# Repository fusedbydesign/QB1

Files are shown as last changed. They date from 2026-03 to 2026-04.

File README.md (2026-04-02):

# QB1

QB1 is a rapid prototyping system for ESP32 devices. The system was designed for ESPHome sensors, but it could potentially be used for other applications.

## Features

* Rapid prototyping for testing sensors and automation in the intended environment.
* Modular design allows each device to be built with the appropriate sensors, power interface, and mounting solutions. The five cube faces can each be used for a different purpose. 
* The QB1 specification allows multiple sensors to exist on the same device without conflict.
* Easy to make. 
  * The enclosure can be produced using a low cost 3D printer. 
  * The main board can be assembled quickly with basic soldering skills.
  * Many common sensor can be integrated by printing a custom face plate and connecting the sensor to the main board with Dupont wire. 
* Once constructed, the device can be modified without soldering, enabling rapid modification of devices. 

## Example Projects

<table>
  <tr>
    <td>
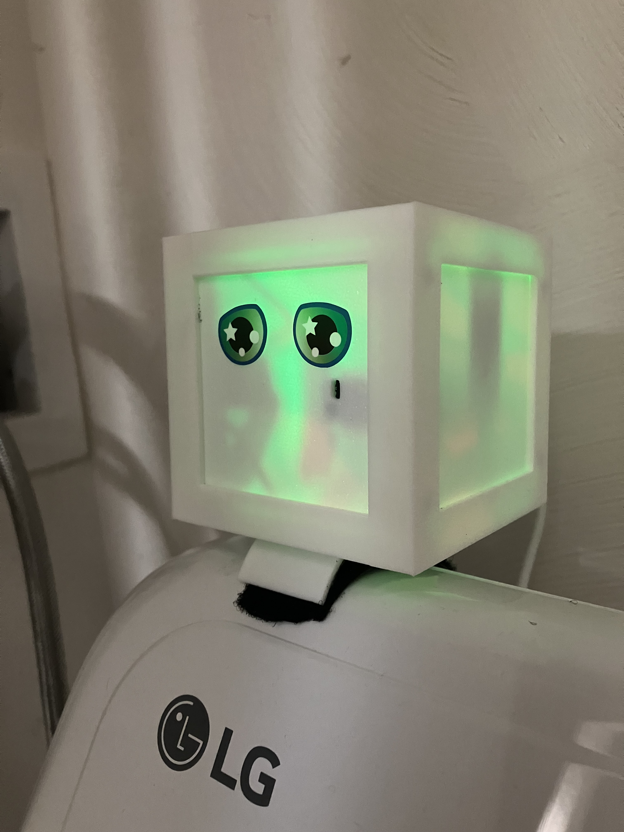
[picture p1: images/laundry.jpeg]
laundry minder project image
      <br>
      Washing machine monitor using SW-420 vibration sensor to detect when the machine is running and V53L0X distance sensor to tell when lid has been opened. The device is mounted to the washing machine using a custom mounting plate and velcro tape, and it is used to send a notification when wet clothes have been left in the wachine machine. 
    </td>
    <td>
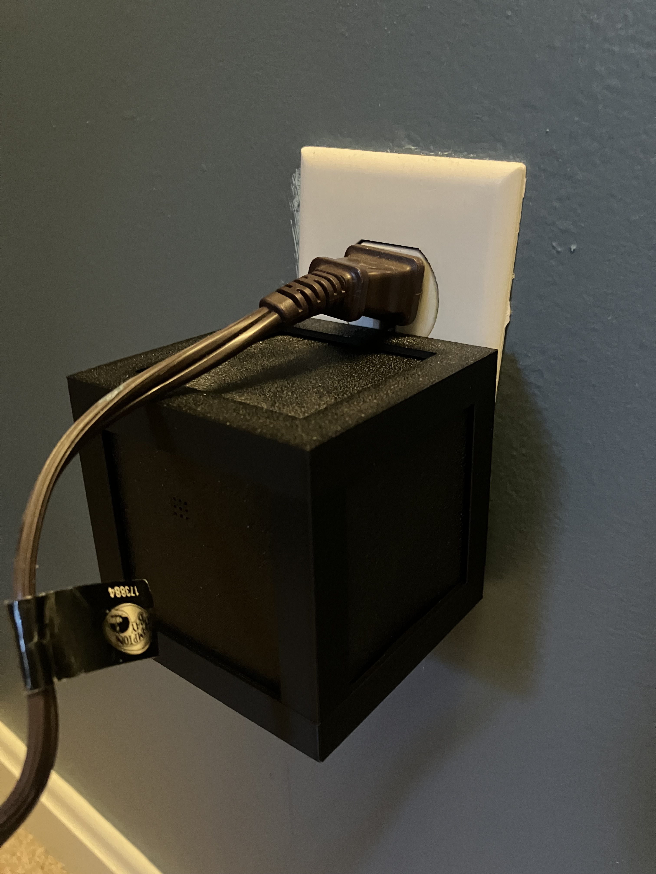
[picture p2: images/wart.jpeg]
wall wart project image
      <br>
      Plug-in temperature and humidity monitor using SHT40. The device plugs in to the wall using an off-the-shelf USB wall plug that is inside the QB1 enclosure and held in place using a custom face plate. 
    </td>
  </tr>

  <tr>
    <td>
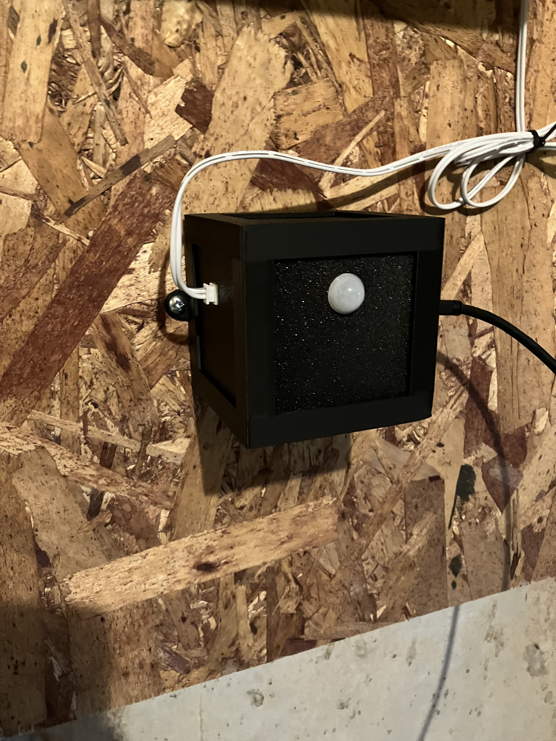
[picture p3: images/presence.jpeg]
human presence project image
      <br>
      A wall-mounted human presence sensor that combines an AM312 PIR motion sensor and a wired magnetic reed door sensor. The device is used turn on/off lights in the area based on human presence. 
    </td>
    <td>
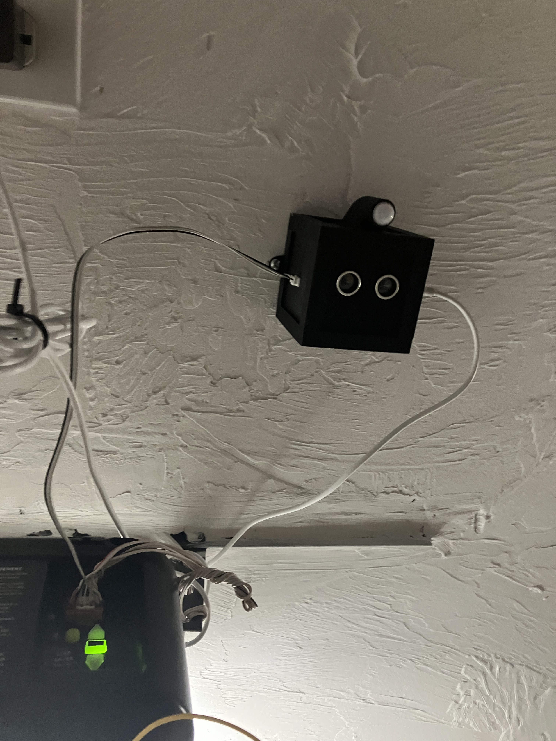
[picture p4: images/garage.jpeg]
garage project image
      <br>
      A ceiling-mounted device that combines human presence detection using an AM312 PIR motion sensor, car presence detection using an HC-SR04 distance sensor, and garage door control/status using a <a href="https://github.com/PaulWieland/ratgdo">ratgdo-compatible</a> peripheral board. 
    </td>
  </tr>
</table>

## Building

The core QB1 components can be built with basic tools and skills. 

> [!WARNING]
> This is an open source project and a constant work in progress, not a finished product. Production files and PCBWay projects are provided only for convenience. Boards ordered using these files/projects may have flaws due to issues in the design or assembly. The maintainers of this project are not responsible for loss or damages due to these flaws. Please submit any issues you find using the issue tracker for this project.  

### Tools Required

* A [soldering iron](https://amzn.to/4105tMp) and related supplies. The QB1 main board contains only through hole components, so only basic soldering skills are required. Some peripheral boards require surface mount components and more advanced soldering skills. 
* A basic 3D printer to print the QB1 enclosure and face plates. Using a print-on-demand service (or a friend with a printer) can help get you started, but having your own printer makes it much easier to print new faceplates to modify the device in the future. The [Bambu Lab A1 Mini](https://bambulab.com/en/a1-mini) (without AMS) is inexpensive and well-suited to printing smaller items like the QB1 enclosure. 
* A small Phillips screwdriver (or driver matching the head of the screws, if not Phillips). The shaft must be smaller than 5.5 mm in diameter in order to fit in the holes in the bottom of the enclosure. 
* A small tube of super glue to build some of the enclosure parts. 
* (Optional) A [hot glue gun](https://amzn.to/40Knkqm). Many sensors that operate at 3.3v can be connected directly to the main board using Dupont wire. It's best to glue these connectors in place so they don't fall off in operation. The hot glue can easily be removed later. 

### Components Required

All components other than custom circuit boards and 3D-printed enclosure parts can be purchased in small quantities from Amazon or AliExpress.

* A QB1 main board. You can order a small batch of 5 main boards using this [PCBWay project](https://www.pcbway.com/project/shareproject/QB1_Main_Board_for_ESP32_Development_Kit_a3892956.html). You can also use the zipped Gerber files provided in a QB1 release to order the board from another supplier. 
* A [30-pin ESP32 development board](https://amzn.to/4lGmVin) with USB-C connector. You can choose a device with the right storage and other features for your application.
* (7) [Female 15-pin, single row board header with 2.54 mm pin spacing](https://amzn.to/4suHbWA). You will need two for the ESP32 dev kit socket and up to 5 for the remaining QB4 faces.
* [Screws](https://amzn.to/47RIYwE): M3, self-tapping, coarse threaded with pan/button head. The head must be between 3.5mm and 5.5mm in diameter.
  * (8) To secure the main board and close the case, use screws that are 8mm long (not counting the head), but screws up to 16 mm in length will also work.
  * (4, Optional) To make the top plate removable and functional, use screws that are exactly 8mm long (not counting the head). In most cases, the top plate is not used for sensors or other peripherals, because the four side plates are sufficient. In this case, it can be glued in place, and these screws are unnecessary.
* [Printed enclosure parts](https://makerworld.com/en/collections/23142249-qb1): A top, a bottom, face plates for mounting and peripherals, and blank plates to cover any remaining faces. 
* (Optional) Any additional components required for peripherals. See peripheral doc for mor information. Some generally useful items to have on hand are:
  * [Dupont wire](https://amzn.to/4slY8CT) with male connector on one end and female connector on the other. The wire should be between 10 and 20cm in length. This wire is useful for hooking up small sensors that do not require a QB1 peripheral board. 
  * [Small prototyping boards](https://amzn.to/4sSRvYk) (e.g 40 mm by 60 mm) can be used to develop peripheral boards.  

### Assembling the Boards

Follow the instructions provided to assemble the QB1 [main board](/mainboards/ESP32DK) and any peripheral boards.

### Assembling the QB1

* Insert the ESP32 development board into the pair of 15-pin sockets on the bottom of the QB1 main board. Use the labels on the PCB silk screen to orient the ESP32 board correctly.  
* Place the main board on the tall screw hole supports inside the enclosure bottom. Ensure that the board is oriented correctly so that the ESP32 dev board screw holes rest on the lower supports and the USB-C connector faces the opening on the bottom plate. Screw the main board in place with 4 M3 screws.
* Place the USB-C port cover in the enclosure bottom and glue it in place with super glue. 
* Attach peripherals
  * For peripherals that are attached by wires, plug the connector into the appropriate place in the main board. Secure the connectors in place using hot glue, and attach the peripheral to its custom face plate.  
  * Attach peripheral boards to their custom plates. These boards typically have male header that connects to the main board and is held in place by the enclosure. This connection will be made when the face plates are inserted in a later step.
* Place the QB1 enclosure top upside down on a flat surface.
* Insert a face plate into the QB1 top face. The plate will be held lightly in place by friction against the screw supports. To hold this plate more firmly, place two top plate holders over the plate and screw them in place. 
* Place face plates into the four slots at the top of the enclosure. 
* Place the QB1 enclosure bottom upside down onto the top. To ensure that the peripheral boards are attached correctly to the main board connector: lift each perhipheral board slightly to make the connection, then lower the enclosure bottom after all connections are made. It may be necessary to wiggle the legs of the enclosure top to ensure that they are seated correctly. 
* Screw the bottom to the top using 4 M3 screws. 

## FAQ

* **When would I use this?** QB1 is useful in a few circumstances: 
  * When you want to quickly prototype a device to test its behavior in the intended environment. 
  * When you need multiple sensors in a single device.
  * When you need to deploy sensors in a basement/garage or other utility area where appearance/size is less important.
* **When wouldn't I use this?** There are some limitations:
  * QB1 is nearly 80 mm long on each side. For many applications, a custom board and enclosure would be smaller. 
* **How do I use this for home sensing and automation?** See the [ESPHome site](https://esphome.io) for more information. A typical solution is to set up a [Home Assistant](https://www.home-assistant.io) hub that takes information from QB1 devices (and other sensors). 
* **Does the QB1 look good?** Looks are subjective, but yes. 
* **What sensors are supported?** Any sensor that operates at 3.3v and has a fairly simple interface (a few IO pins, I2C, SPI, etc.) can be wired directly to the appropriate pins on the QB1 main board. Then all that is needed is a face plate that holds the sensor in place. Sensors/components with more complicated interfaces can be integrated by developing a peripheral board with additional interface components. 
* **How do I add an external connector?** The best ways to achieve this are:
  * Locate a panel-mount connector and attach it to the main board using wires.
  * Make a simple peripheral board with connectors soldered to it. A male JST-XH connector soldered to a peripheral board will sit approximately flush with the face plate. 
* **How do I configure ESPHome?** Locate ESPHome documentation for the sensor you would like to configure. Look at the main board documentation or silk screen markings on the main board to determine which pins are attached to each connector position. 
* **What happens if I plug in multiple peripherals? How do I keep them from conflicting?** The QB1 spec assigns pins to each peripheral position. Some pins are shared, such as pins intended for the I2C and SPI buses. Each peripheral position also has four pins that are dedicated to that position (with the exception of EB2 and EB5, that have the same set of "dedicated" pins). Where possible, a peripheral should use dedicated pins or buses in order to avoid conflict.
* **The screws are too tight/loose. What is wrong?** To keep the part count low, the design does not use screw inserts, and instead uses self-tapping screws that screw into 3D-printed holes. Due to variation in printers and settings, these holes may be slightly too large/small. To fix it:
  * If the hole is too tight, carefully drill it out. Forcing the screw in without drilling may cause the plastic to crack.
  * If the hole is too loose, add a small amount of hot glue, allow the glue to cool, then screw in the screw. Hot glue can also be used to repair screw holes that are cracked or worn out. 
* **What options should I select when ordering boards from PCBWay?** Unless you have a compelling reason to change the options, you can use the default settings when ordering boards. 
* **How can I get a QB4 if I don't have a 3D printer or soldering iron?** There are a few options:
  * Order assembled boards and printed enclosure parts from an electronics fab and print-on-demand service, respectively.
  * Join a local maker space that has 3D printers and electronics assembly tools. 
  * Find someone near you with a 3D printer and buy enclosure parts from them. Many people who own a 3D printer would be thrilled to print something for you in exchange for a small amount of money to pay for their filament habit. 
  * Use this project as an excuse to buy what you need. Soldering supplies are inexpensive. Small/basic 3D printers are now cheap and reliable enough that they should be considered essential tools for any homeowner. 

## Support and Transparency

If you are fortunate enough to have a store near you that sells basic electronics components, please consider buying components from them instead of using the links on this site or ordering from internet retailers.

I (the developer of QB1) earn a commission from tools and components purchased though links on this site. As an Amazon Associate, I earn from qualifying purchases. I also earn a commission from circuit boards ordered from PCBWay. I chose the recommended tools/components by searching for products with the correct specs and features, but I haven't tried them all. Please review the product description, specs, reviews, etc. before ordering.

If you would like to directly support the development of QB1, you can donate using [Buy me a coffee](https://buymeacoffee.com/fusedbydesign).

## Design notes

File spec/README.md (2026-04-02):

# QB1 Specification

The QB1 specification governs the physical and electrical characteristics of QB1 and its peripherals. The specification ensures that compliant peripherals will fit in the enclosure and will not interfere with other peripherals. 

## Electrical Specification

### Peripheral Connector Pins

The 15-pin peripheral connector has the following pin connections:

| Pin # | Name | Description |
|---|---|---|
| 1 | AUX | Auxiliary connection shared between all peripherals, not connected to ESP32 |
| 2 | S | Shared connection between all peripherals and connected to ESP32 |
| 3 | MOSI | SPI MOSI |
| 4 | MISO | SPI MISO |
| 5 | CLK | SPI CLK |
| 6 | EN | ESP32 enable pin which allows the peripheral to reset the ESP32 |
| 7 | SCL | I2C SCL |
| 8 | SDA | I2C SDA |
| 9 | 3V3 | 3.3V power|
| 10 | GND | Ground |
| 11 | VIN | 5V power|
| 12 | PIO4 | Peripheral I/O 4 |
| 13 | PIO3 | Peripheral I/O 3 |
| 14 | PIO2 | Peripheral I/O 2 |
| 15 | PIO1 | Peripheral I/O 1 |

The mapping between these pins and ESP32 pins is not part of the spec, and is specific to each main board implementation. This mapping can be found in the main board documentation. 

#### AUX

The AUX pin is intended to carry power/signals between all peripherals without using the host. For example, it could carry an analog signal or higher voltage/current power. The use of this pin is not governed by the spec. 

#### S

The S pin carries a signal that is shared between all peripherals and the host. The use of this pin is not governed by the spec.

#### SPI Pins

The MOSI, MISO, and CLK pins are used to construct a SPI bus controlled by the host. The slave select (SS) should be implemented using a PIO pin, so it will be different for each peripheral. A spec-compliant peripheral should only use the MOSI, MISO and CLK pins as a full duplex, single-width SPI bus.  

#### I2C Pins

The SCL and SDA pins are used to construct an I2C bus controlled by the host.  A spec-compliant peripheral should only use these pins as an I2C bus. The spec does not govern how addresses are assigned, and peripherals should support address changes to allow multiple peripherals of the same type to be attached at the same time. 

#### Power Pins

The 3V3 pin provides 3.3V during operation. The VIN pin may provide 5V, or it may be unconnected, depending on the configuration. The user must ensure that only one power supply is connected to either VIN or 3V3, originating from the main board or a peripheral. When 5V is supplied to VIN, the main board will produce 3.3V and supply it to the 3V3 pin.  

#### PIO Pins

The peripheral I/O (PIO) pins are used to make a separate connection between the host and each peripheral in a standardized way. For example, two peripherals can be installed that both use PIO1 and PIO2 to communicate directly with the host. These pins will be mapped to different host pins for each peripheral location. 

The PIO pins have the following features and allowed uses:

| PIO # | Input to host | Output from host | Internal pull-up | Analog input to host | Capacitive touch input to host | 
|:---:|:---:|:---:|:---:|:---:|:---:|
| PIO 1 | X | X | X | | |
| PIO 2 | X | X | X | X | X |
| PIO 3 | X | | | | |
| PIO 4 | (1) | X | (1) | (1) | (1) |

1. PIO 4 supports input to the host with pull-up, analog, and touch, but it may also be connected to strapping pins on the host, requiring it to be in a high-impedance state during host boot. This pin shall only be used as an input to the host after the host has booted. 

### Power

The specification allows two power configurations:
* In the full power configuration, power is supplied to both the 5V and 3.3V rails. All spec-compliant peripherals can be used in this configuration.
* In the low power configuration, power is only fully supplied to the 3.3V rail. This configuration should be used when the device is powered by a battery, or otherwise has power limitations. Peripherals should work in low power mode, if possible, but this mode will not support peripherals that require 5V. A low power device may supply power to the 5V rail, but attached low-power peripherals must not draw power from this rail.  

#### Supply

A compliant power source must supply exactly one of the following to the QB1 main board:
* 5V at 2A (full power)
* 3.3V at 1A (low power)

#### Draw

A compliant peripheral must draw at most:
* 5V at 200mA
* 3.3V at 100mA

A single peripheral may draw from both power rails simultaneously. In order to support the low power configuration, a peripheral should not draw power from the 5V rail. 

If a peripheral requires more power than allowed by the spec, it may power itself and also act as a power supply to the QB1. For example, the peripheral could accept 5V at 3A, use 1A for its purposes, and provide the remaining 2A to the QB1 via VIN. The power supply could also send power to other peripherals using AUX, but the use of AUX for this purpose is outside of the spec. 

#### Absolute Maximum

The absolute maximum voltage and current that may be supplied over AUX is 12V and 3A. 

## Physical Specification

The physical specification is a set of dimensions that affect peripheral fit.

| Dimension | Value | Notes| 
|---|---|---|
| A | 3.4 mm | Distance from center of peripheral connector to inside of window plate. |
| C | 2 mm | Window plate thickness |
| D | 50 mm | Usable window height and width |
| E | 34 mm | Usable window height above main board connector |
| F | 62 mm | Maximum peripheral board width |
| G | 38 mm | Maximum distance from top of main board connector to top of peripheral board |
| H | 6 mm  | Maximum distance from top of main board connector to bottom of peripheral board |
| I | 2.4mm | Maximum peripheral board thickness |

Additional notes:
* When a peripheral board is mounted in the inside position, it may interfere with adjacent boards if it is wider than 40mm. 
* A peripheral board mounted in the inside position of the top plate may interfere with boards mounted in side plates that are taller than 28mm from the top of the main board connector. 
* A peripheral board mounted in the outside position of the top plate may interfere with boards mounted in side plates that are taller than 36mm from the top of the main board connector. 
* The spec does not govern the use of space behind the peripheral board. For best results, peripherals should use space toward the center of the usable window area, and provide options that help prevent interference with nearby peripherals (e.g. multiple face plates that place the peripheral in slightly different positions).

## Component Guidelines

Where possible, QB1 main boards, peripherals, and enclosure pieces should allow component sourcing and assembly by hobbyists. This section contains guidelines, but these are not required to be followed for spec compliance. 

* When screws are required, use M3 self-tapping coarse thread screws with 8mm of thread length. 
* Use through-hole electronic components, if possible.

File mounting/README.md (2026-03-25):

# QB1 Mounting

This document lists QB1 mounting hardware and other physical solutions.

## Mounting

* A face plate is available that allows the QB1 to be [mounted to a wall or ceiling](https://makerworld.com/en/models/2566908-qb1-wall-ceiling-mount-plate) using screws.

## Miscellaneous

* QB1 faces that are not used for peripherals or mounting can be covered with [blank face plates](https://makerworld.com/en/models/2543181-qb1-blank-face-plate).

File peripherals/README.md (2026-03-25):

# QB1 Peripherals

This document lists peripherals that are supported by QB1. This list is not comprehensive, and adding support for a 3.3v sensor is usually a simple matter of developing a face plate for it. 

## Sensors

### Distance

* [HC-SR04](HCSR04). An ultrasonic distance sensor with a range of 2cm to 4m and an accuracy of 3mm. Interfaces to QB1 using a peripheral board. 
* [VL53LOX](https://makerworld.com/en/models/2572612-qb1-vl53lox-plate). A time-of-flight laser distance sensor with a range of 30mm to 2m and an accuracy of +/- 3%. Connects directly to QB1 using wires. 

### Motion/Presence

* [AM312](https://makerworld.com/en/models/2547169-qb1-am312-plate). A PIR motion sensor that detects humans and pets up to 5m away. Connects directly to QB1 using wires. An [angled mounting plate](https://makerworld.com/en/models/2548871-qb1-am312-plate-angled) is also available.

### Environmental

* [SHT40](https://makerworld.com/en/models/2571182-qb1-sht40-plate). A temperature and humidity sensor with an accuracy of +/- 0.2 degrees C and +/- 1.8% RH. Connects directly to QB1 using wires. 

### Vibration  

* [SW-420](https://makerworld.com/en/models/2572635-qb1-sw-420-plate) vibration sensor. Connects directly to QB1 using wires.

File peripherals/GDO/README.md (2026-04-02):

# Garage Door Opener Board for QB1

The Garage Door Opener (GDO) board allows the QB1 to directly interface with Chamberlain/Liftmaster garage door openers that cannot be controlled with dry contacts. 

This peripheral is inspired by the [ratgdo](https://ratcloud.llc), and it is designed to be compatible with [ratgdo firmware](https://paulwieland.github.io/ratgdo/flash.html). If you simply want to connect your garage door opener to your home automation system, please consider buying a ratgdo board. Some models even include additional components that make it easy to solve additional garage sensing/control problems (car presense, parking distance) with the ratgdo. The QB1 GDO peripheral is designed for circumstances in which a ratgdo needs to be combined with other sensors/peripherals. It can also be used to address unusual power or mounting circumstances. 

The schematic and technical information used to develop this project are due to the [rat-ratgdo project](https://github.com/Kaldek/rat-ratgdo). 

## Printed Circuit Board

The easiest way to get the PCB is to order a batch using this [PCBWay project](https://www.pcbway.com/project/shareproject/QB1_garage_door_opener_peripheral_board_5e12e1d1.html). This project can also be used to purchase assembled boards. 

> [!CAUTION]
>Assembling this peripheral is somewhat challenging because it is necessary to obtain and solder surface mount components. The soldering is possible with a normal soldering iron with a fine tip. Search on YouTube for instructional videos. You will probably also want additional tools such as a vise, a desk-mounted magnifying glass, and tweezers. 

## Required components

| Count | Description |
|---|---|
| 1 | 3-pin male JST-XH PCB connector, through hole, straight |
| 1 | 2N7002 transistor, surface mount, SOT-23 |
| 2 | AO3400A transistor, surface mount, SOT-23 |
| 3 | 10k Ohm resistor, surface mount, 0805, 1%, 1/4W |
| 1 | 15-pin male header with 2.54mm spacing, angled, 6mm mating length, 3mm tail length |
| 1 | (Optional) 2-pin male header with 2.54mm spacing, straight, 6mm mating length, 3mm tail length| 
| 1 | (Optional) 2-pin jumper with 2.54mm spacing | 

It is also necessary to obtain a wire to connect the peripheral to the terminals on the garage door opener. The best way to do this is to crimp a female JST-XH connector onto one end of a ribbon or set of wires, and leave the other end bare so the wires can be attached to the terminals on the garage door opener. See the board silk screen to determine the proper connections. 

## Assembly

1. Place and solder the the surface mount components on the front side of the board. 
1. Place and solder the 3-pin JST connector, after selecting the appropriate location. 
  * To allow the peripheral to be installed in a side face of the QB1 (the most common mounting), the connector should placed in the location marked J4 on the back side of the board.
  * The connector can be soldered in other positions, or even left off the board, to support less common methods of mounting the board and connecting to the garage door opener. 
1. Place and solder the 15-pin angled header on the front side of the board. The board may not have silk screen markings to indicate the correct side of the board for the header. It should be placed on the same side as the surface mount components.  
1. (Optional) place and solder the 2-pin male jumper at position J2 on the front of the board. 

The 2-pin male header is used to optionally connect the CTRL signal from the garage door opener to the QB1 AUX line. This optional connection can be made by placing a jumper on the header. The connection allows other peripherals to use the CTRL signal (e.g. to make a power supply).

The peripheral board mounts to the main board in the outside position, which allows the JST-XH connector to sit roughly flush with the window. 

## Enclosure

A [face plate](https://makerworld.com/en/models/2606454-qb1-plate-for-garage-door-opener-peripheral-board) is available for this peripheral. Attach the peripheral board to the face plate using 4 M3x8mm self-tapping screws. 

## Operation

The easiest way to use the GDO peripheral is to start with the appropriate [ratgdo firmware](https://paulwieland.github.io/ratgdo/flash.html) and modify the configuration so that the firmware communicates with the GDO using the correct pins. See the silk screen on the peripheral board for the connection between the GDO and QB1 connector. Also see the [main board README](/mainboards/ESP32DK) for the mapping between QB1 connector pins and ESP32 pins.  

The ESPHome ratgdo firmware is available on github, and there is also a convenient [downloader](https://ratgdo.github.io/esphome-ratgdo/). Any firmware that uses the correct host SoC family (e.g. ESP32 for the QB1 ESP32 dev kit main board) should work after the pins are correctly configured. The ESPHome configuration can then be modified to enable additional peripherals on the device.

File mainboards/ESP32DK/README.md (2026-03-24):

# QB1 ESP32 Dev Kit Main Board

The ESP32 Dev Kit Main Board adapts a 30-pin ESP32 dev dev to the QB1. This is the main component required to build a QB1 using an ESP32 dev kit. 

## Printed Circuit Board

The easiest way to get the PCB is to order a batch using this [PCBWay project](https://www.pcbway.com/project/shareproject/QB1_Main_Board_for_ESP32_Development_Kit_a3892956.html). You can also get an assembled board, but the board has been designed to make DIY component sourcing and assembly very easy.  

## Required components

| Count | Description |
|---|---|
| 7 | Female header with 2.54mm spacing, 15-pin |

## Assembly

* Solder 15-pin female header connectors to the locations on indicated for the ESP32 dev kit, and also to any peripheral locations that will be used. Note that connectors for the dev kit go on the bottom of the board, while the connectors for the peripherals go on the top. Use the PCB silk screen as a guide, and only place connectors where the holes are surrounded by a border on the silk screen.  
* Solder additional connectors for power and reset connections, as needed. In many cases, these connectors are unnecessary. These connectors are only necessary if you want to add a poer source or reset switch without using one of the peripheral spots.  

## Enclosure

Print or otherwise obtain the [enclosure bottom](https://makerworld.com/en/models/2543156-qb1-bottom-for-esp32-dev-kit-main-board) to incorporate this main board into a QB1. To complete the enclosure, you will also need a top piece and window pieces/blanks. All QB1 enclosure pieces are available in [this collection](https://makerworld.com/en/collections/23142249-qb1).

## Operation

### Power

Power can be supplied to this board through the USB connector on the development kit, or by a power supply peripheral. When powering by USB, the USB power supply must provide at least 2A for the full power configuration, or 1A for low power configuration. See the [QB1 specification](/spec) for more information about power configurations. 

### Connectors

This main board has four peripheral connectors labeled EB1-5. EB5 is in the center of the board, and it can be used to wire up a peripheral mounted to the top plate. All connectors are wired to different host pins for PIO, except for EB2 and EB5, which share the same host pins for PIO. So peripherals that use (the same) PIO pins cannot operate in EB2 and EB5 at the same time. 

### Pin Mapping

| Pin # | Connector | Host |
|---|---|---|
| 1 | AUX | Not Connected |
| 2 | S | D25 |
| 3 | MOSI | D23 |
| 4 | MISO | D19|
| 5 | CLK | D18 |
| 6 | EN | EN |
| 7 | SCL | D22 |
| 8 | SDA | D21 |
| 9 | 3V3 | 3V3 |
| 10 | GND | GND |
| 11 | VIN | VIN |

| Pin # | Connector | Host EB1 | Host EB2 | Host EB3 | Host EB4 | Host EB5 |
|---|---|---|---|---|---|---|
| 12 | PIO4 | D12 | D4 | D2 | D15 | D4 |
| 13 | PIO3 | D36 | D39 | D34 | D35 | D39 |
| 14 | PIO2 | D27 | D13 | D14 | D33 | D13 |
| 15 | PIO1 | D16 | D17 | D26 | D32 | D17 |

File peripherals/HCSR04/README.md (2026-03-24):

# HC-SR04 Distance Sensor Peripheral Board for QB1

The HC-SR04 is a low-cost ultrasonic distance sensor with sub-centimeter precision and a maximum range of 4 meters. Unfortunately, it needs to operate at 5V for best performance, and its output must be converted to 3.3V in order to interface with the ESP32 without damaging it. This board provides a safe, reliable 5v/3.3V interface between the ESP32 and an HC-SR04. The board also provides a physical mounting surface for the HC-SR04, and a second level converter that can be used to connect another HC-SR04 that is mounted elsewhere. 

> [!TIP]
> There are other distance sensors that can interface more easily with the QB1 without level conversion. There are also HC-SR04P modules that can be powered using 3.3v, but the maximum range will be slightly reduced. Be prepared to test multiple distance sensors to find the ones that work best for your application.

## Printed Circuit Board

The easiest way to get the PCB is to order a batch using this [PCBWay project](https://www.pcbway.com/project/shareproject/QB1_peripheral_board_for_HC_SR04_distance_sensor_22c7cf84.html). Due to the options for mounting the sensor module, and the unusual way the module is mounted in some options, DIY assembly is highly recommended. Assembly only requires a few through hole components and some basic soldering skills. 

## Required components

| Count | Description |
|---|---|
| 1 | [HC-SR04 module](https://amzn.to/4rNMYFK)|
| 1 | 15 pin male header, 2.54mm pin spacing, angled |
| 2 | 100k Ohm resistor, through hole, axial |
| 2 | 51k Ohm resistor, through hole, axial |
| 4 | Single pin male header, straight |
| 1 | (Optional) 4-pin male header, 2.54mm spacing, angled | 

Component notes:
* For the angled header, you can use commonly-available [breakaway header](https://amzn.to/4sulC8Q) and break it to the correct size. Ensure the header has a short post (the straight part---approximately 3mm long) and a longer tail (the bent part---approximately 6mm long after the bend). The post of the header is soldered to the board and the connector sits 4-5mm off the board. These dimensions ensure a proper fit using the face plate for this connector. Other connectors may be used by modifying the face plate.
* Any [resistors](https://amzn.to/4bEVNeX) with 5% or smaller tolerance and at least 1/4 watt power capacity will work. You can modify the resistance to match the resistor values you have available, as long as the ratio remains approximately 1:2. For example, a 47k Ohm reistor can be used instead of 51k. Increasing the resistance (while maintaining a ratio of 1:2) is not recommended, but the values can be lowered to a minimum of 1k/2k, if desired. The value of 51k/100k was chosen to give acceptable performance in most environments while minimizing power draw. If the sensor will be used in an environment with a large amount of electromagnetic interference, then lower resistance values may give more reliable performance, at the expense of slightly more power draw.

## Assembly

The board supports two different orientations for the HC-SR04:
* Straight mount so that the HC-SR04 and board occupy a single cube face. This is the most common orientation.
* Edge mount so the board can be mounted in one of the side faces and the HC-SR04 points in the direction of the top face. This orientation allows the HC-SR04 to point in the direction of the top face, without the complications associated with mounting the board on the top face. 

Take note of the order in which the components must be placed and soldered---the HC-SR04 covers some of the other components, so it must be placed last. To assemble:

1. Place and solder the resistors as shown in the silk screen on the back of the board, and the 15-pin header on the front of the board.  
1. If the second interface will be used to connect a second HC-SR04 to the QB1, place and solder the 4-pin angled header.
1. Attach the HC-SR04 module and related components
  * For straight mount, start by placing and soldering the single pin headers on the front side of the board, as shown in the silk screen. These headers are not connected, and are only used for structural support. Next, bend the pins on the HC-SR04 module to make them straight, then place the HC-SR04 module, ensuring the pins on the single headers extend through the mounting holes at the corners of the module. With the module seated flush against the base of the headers, solder the module pins to the board. Finally, cut the excess pin length from the module pins and single pin headers using wire cutters. 
  * For edge mount, place and solder the HC-SR04 module in the U2 position on the back of the board, with the sensor pointing away from the board. Cut the excess pin length from the HC-SR04 connector.
  
The peripheral board mounts to the main board in the inside position, in order to accommodate the depth of the sensor module. 

## Enclosure 

Print or otherwise obtain the [face plate](https://makerworld.com/en/models/2567128-qb1-face-plate-for-hc-sr04-peripheral-board) to incorporate this peripheral board into a QB1. To complete the enclosure, you will also need other pieces from [this collection](https://makerworld.com/en/collections/23142249-qb1).

## Operation

For the HC-SR04 mounted to the peripheral board, the trigger pin is connected to TRIG1, and and the echo pin is connected to ECHO1. For the optional external HC-SR04, these signals are TRIG2 and ECHO2. See the silk screen on the board for the connection between these signals and QB1 peripheral pins. 

See the [ESPHome](https://esphome.io/components/sensor/ultrasonic/) page on ultrasonic distance sensors for more information about the HC-SR04 and how to use it with ESPHome.

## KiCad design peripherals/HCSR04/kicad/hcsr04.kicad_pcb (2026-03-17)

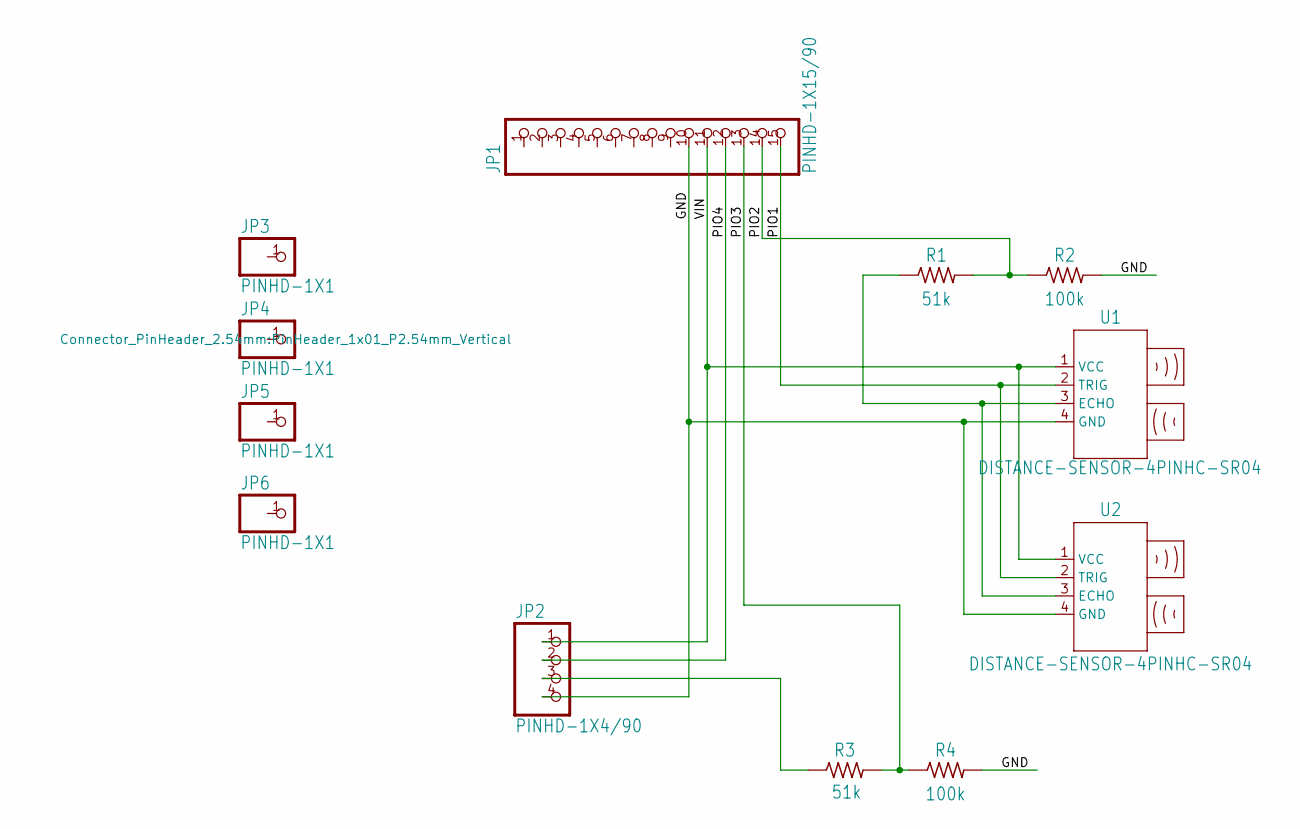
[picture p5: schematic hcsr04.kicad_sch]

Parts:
JP1: PINHD-1X15/90; PinHeader_1x15_P2.54mm_Horizontal
JP2: PINHD-1X4/90; PinHeader_1x04_P2.54mm_Horizontal
JP3, JP4, JP5, JP6: PINHD-1X1; PinHeader_1x01_P2.54mm_Vertical
R1, R3: 51k; R_Axial_DIN0207_L6.3mm_D2.5mm_P7.62mm_Horizontal
R2, R4: 100k; R_Axial_DIN0207_L6.3mm_D2.5mm_P7.62mm_Horizontal
U1, U2: DISTANCE-SENSOR-4PINHC-SR04; HC-SR04

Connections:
/GND: JP1.10, JP2.4, R2.2, R4.2, U1.4 (GND), U2.4 (GND)
/PIO1: JP1.14, JP1.15, R1.2, R2.1, U1.2 (TRIG), U2.2 (TRIG)
/PIO3: JP1.13, R3.2, R4.1
/PIO4: JP1.12, JP2.2
/VIN: JP1.11, JP2.1, U1.1 (VCC), U2.1 (VCC)
unnamed: JP2.3, R3.1
unnamed: R1.1, U1.3 (ECHO), U2.3 (ECHO)

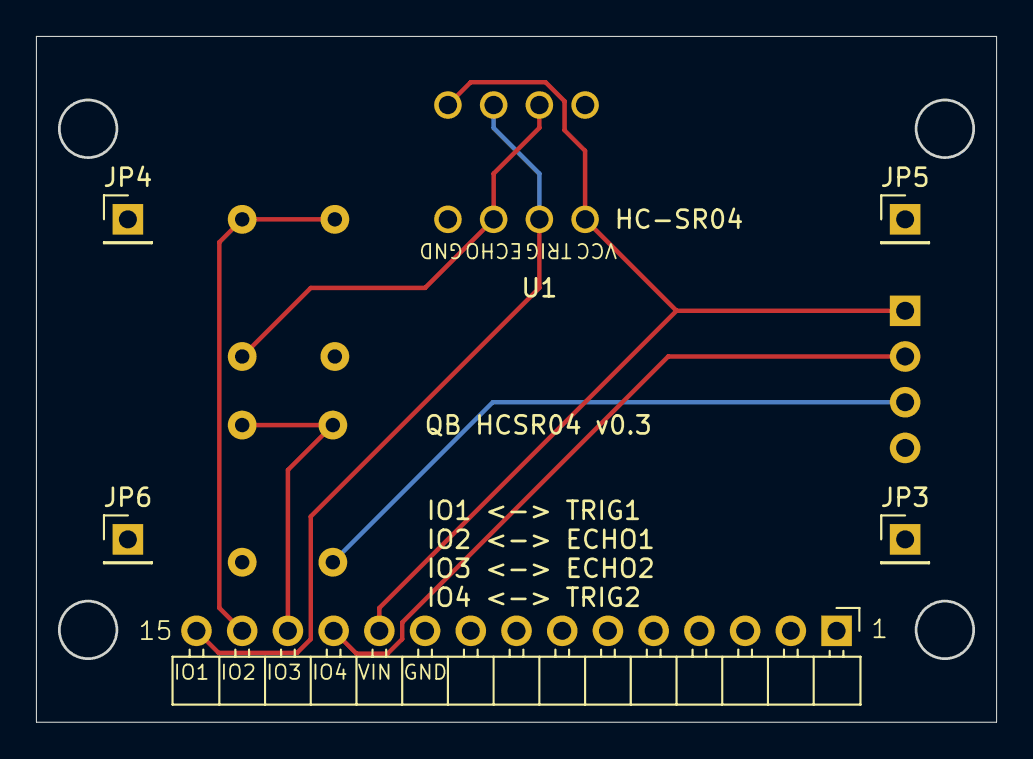
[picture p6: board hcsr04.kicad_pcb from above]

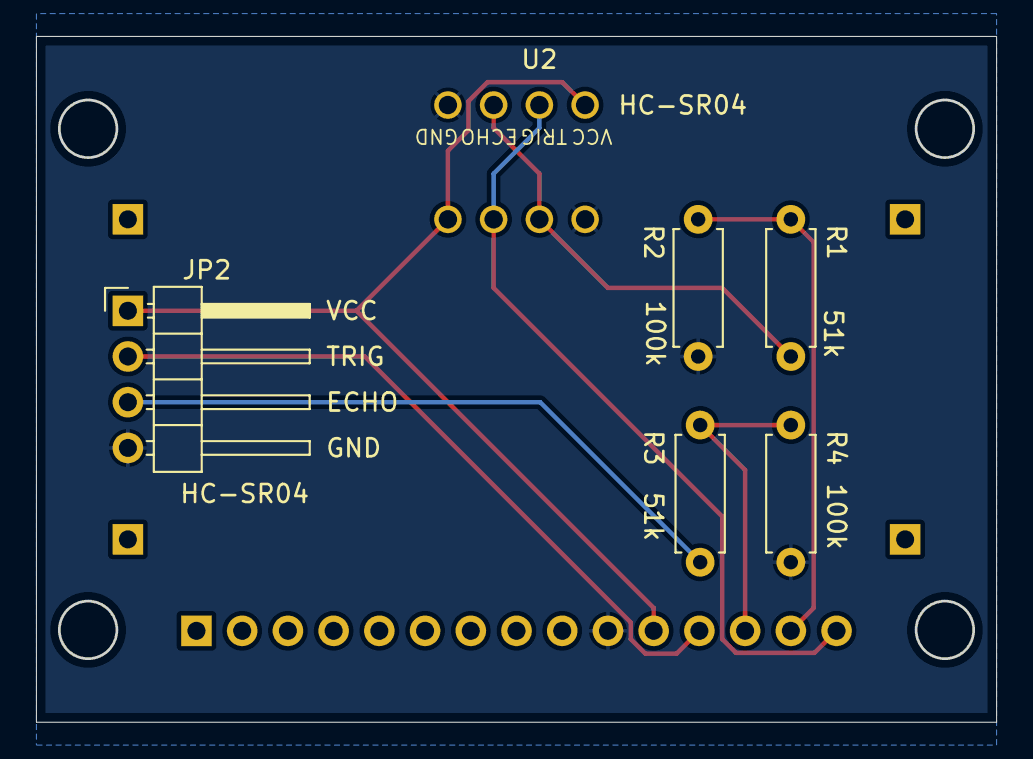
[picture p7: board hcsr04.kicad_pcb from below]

Board: 2 copper layers, 53.3 x 38.1 mm, 12 parts (6 on the bottom side), 7 nets.

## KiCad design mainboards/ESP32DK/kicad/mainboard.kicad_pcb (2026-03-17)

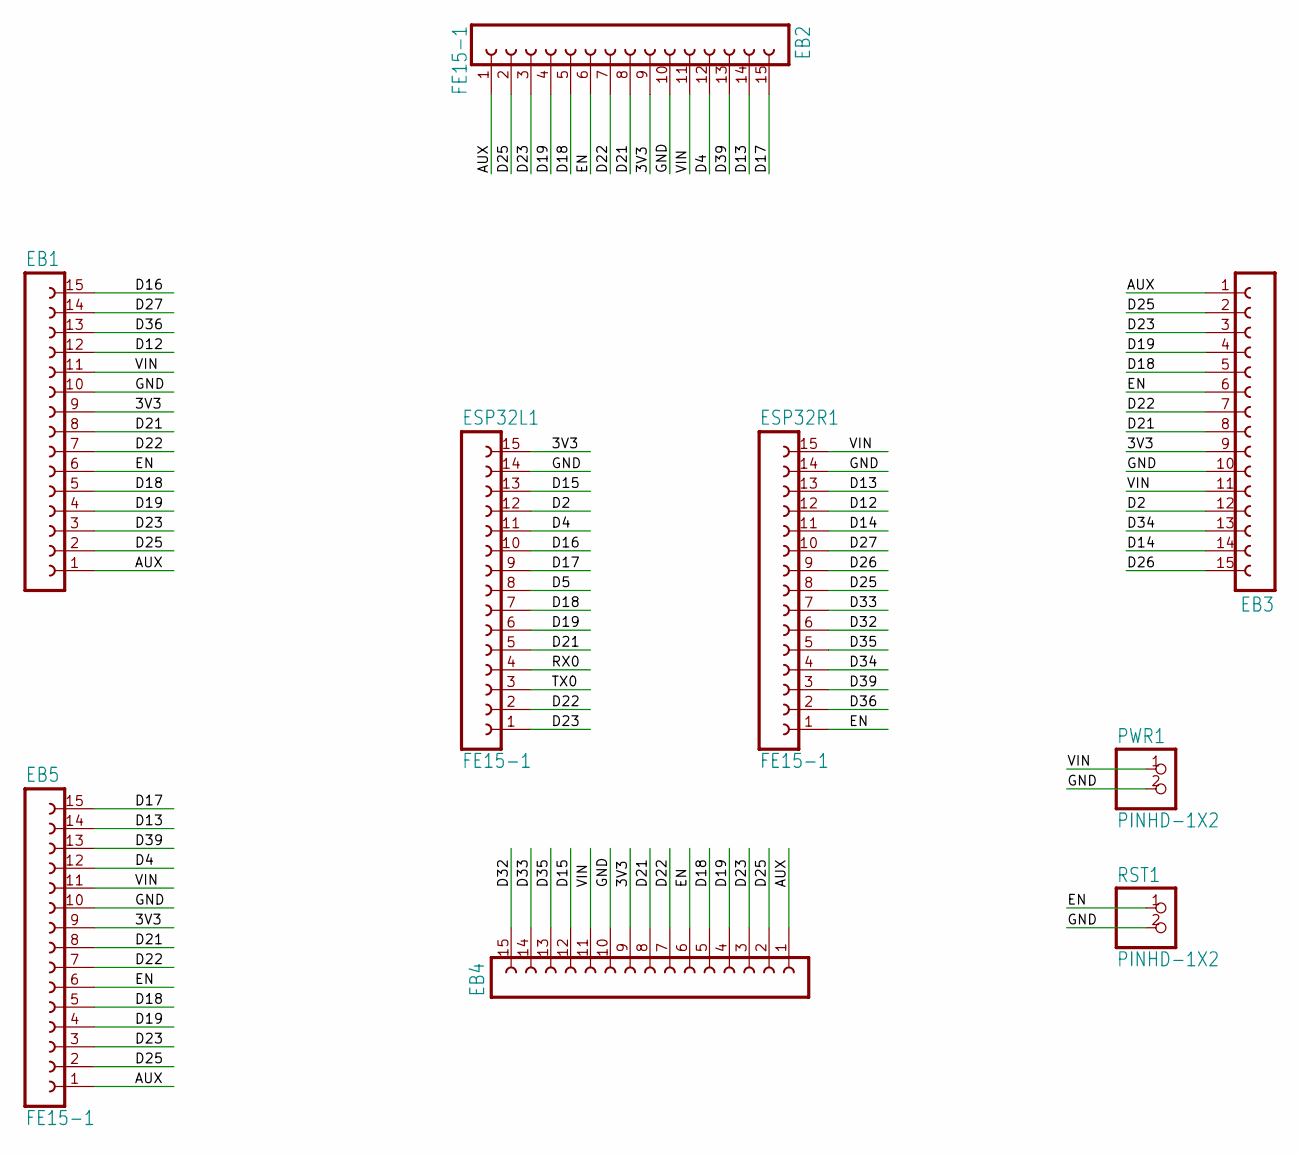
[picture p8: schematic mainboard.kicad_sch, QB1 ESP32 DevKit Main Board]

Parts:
EB1, EB3, EB4: PinSocket_1x15_P2.54mm_Vertical
EB2, EB5: FE15-1; PinSocket_1x15_P2.54mm_Vertical
ESP32L1, ESP32R1: FE15-1; PinSocket_1x15_P2.54mm_Vertical
PWR1: PINHD-1X2; PinHeader_1x02_P2.54mm_Vertical
RST1: PINHD-1X2; PinHeader_1x02_P2.54mm_Vertical

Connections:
/3V3: EB1.9, EB2.9, EB3.9, EB4.9, EB5.9, ESP32L1.15
/AUX: EB1.1, EB2.1, EB3.1, EB4.1, EB5.1
/D2: EB3.12, ESP32L1.12
/D4: EB2.12, EB5.12, ESP32L1.11
/D5: ESP32L1.8
/D12: EB1.12, ESP32R1.12
/D13: EB2.14, EB5.14, ESP32R1.13
/D14: EB3.14, ESP32R1.11
/D15: EB4.12, ESP32L1.13
/D16: EB1.15, ESP32L1.10
/D17: EB2.15, EB5.15, ESP32L1.9
/D18: EB1.5, EB2.5, EB3.5, EB4.5, EB5.5, ESP32L1.7
/D19: EB1.4, EB2.4, EB3.4, EB4.4, EB5.4, ESP32L1.6
/D21: EB1.8, EB2.8, EB3.8, EB4.8, EB5.8, ESP32L1.5
/D22: EB1.7, EB2.7, EB3.7, EB4.7, EB5.7, ESP32L1.2
/D23: EB1.3, EB2.3, EB3.3, EB4.3, EB5.3, ESP32L1.1
/D25: EB1.2, EB2.2, EB3.2, EB4.2, EB5.2, ESP32R1.8
/D26: EB3.15, ESP32R1.9
/D27: EB1.14, ESP32R1.10
/D32: EB4.15, ESP32R1.6
/D33: EB4.14, ESP32R1.7
/D34: EB3.13, ESP32R1.4
/D35: EB4.13, ESP32R1.5
/D36: EB1.13, ESP32R1.2
/D39: EB2.13, EB5.13, ESP32R1.3
/EN: EB1.6, EB2.6, EB3.6, EB4.6, EB5.6, ESP32R1.1, RST1.1
/GND: EB1.10, EB2.10, EB3.10, EB4.10, EB5.10, ESP32L1.14, ESP32R1.14, PWR1.2, RST1.2
/RX0: ESP32L1.4
/TX0: ESP32L1.3
/VIN: EB1.11, EB2.11, EB3.11, EB4.11, EB5.11, ESP32R1.15, PWR1.1

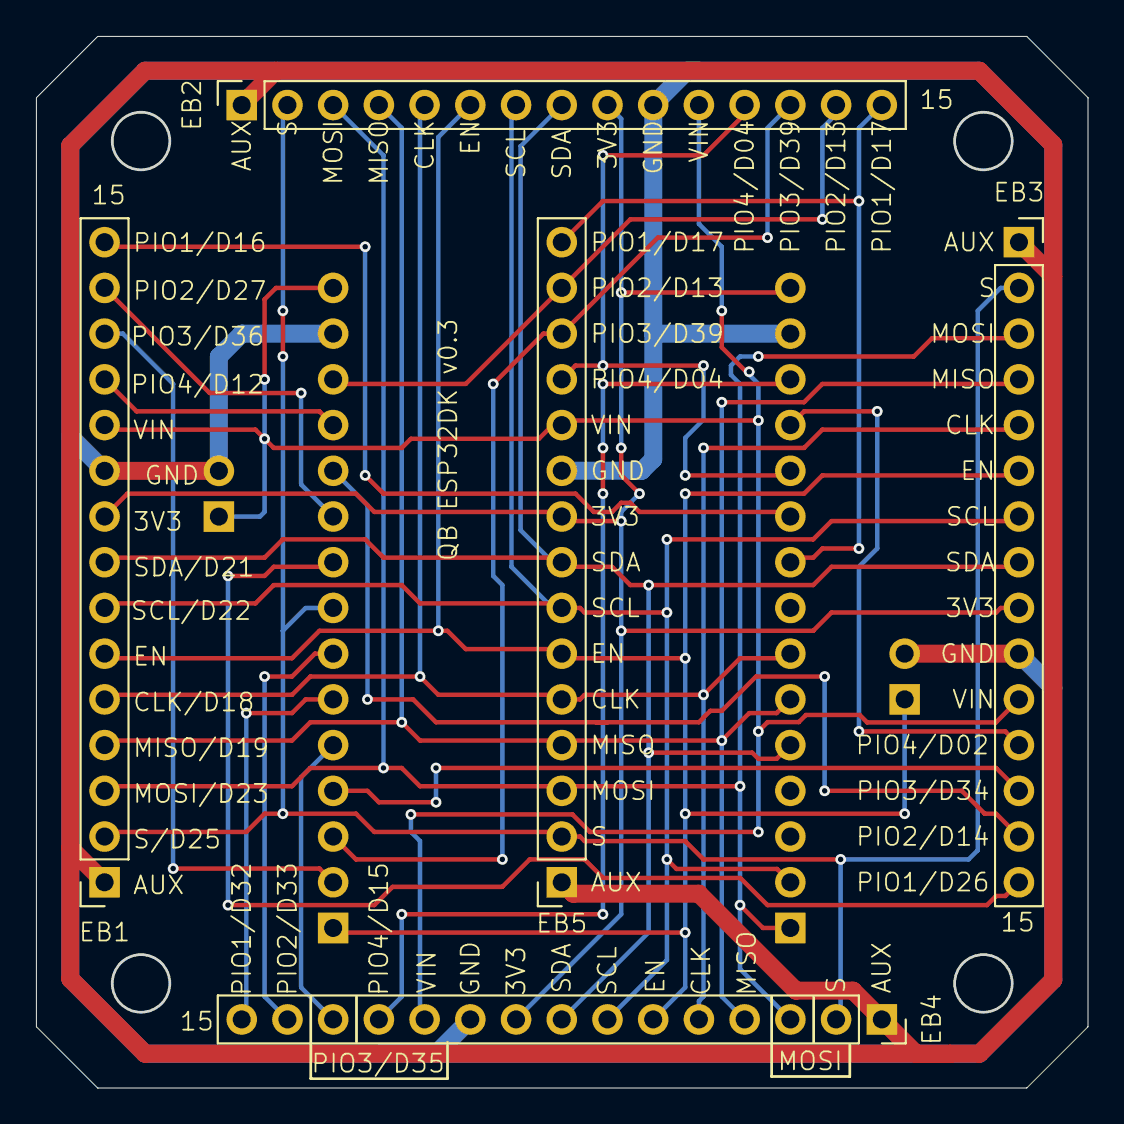
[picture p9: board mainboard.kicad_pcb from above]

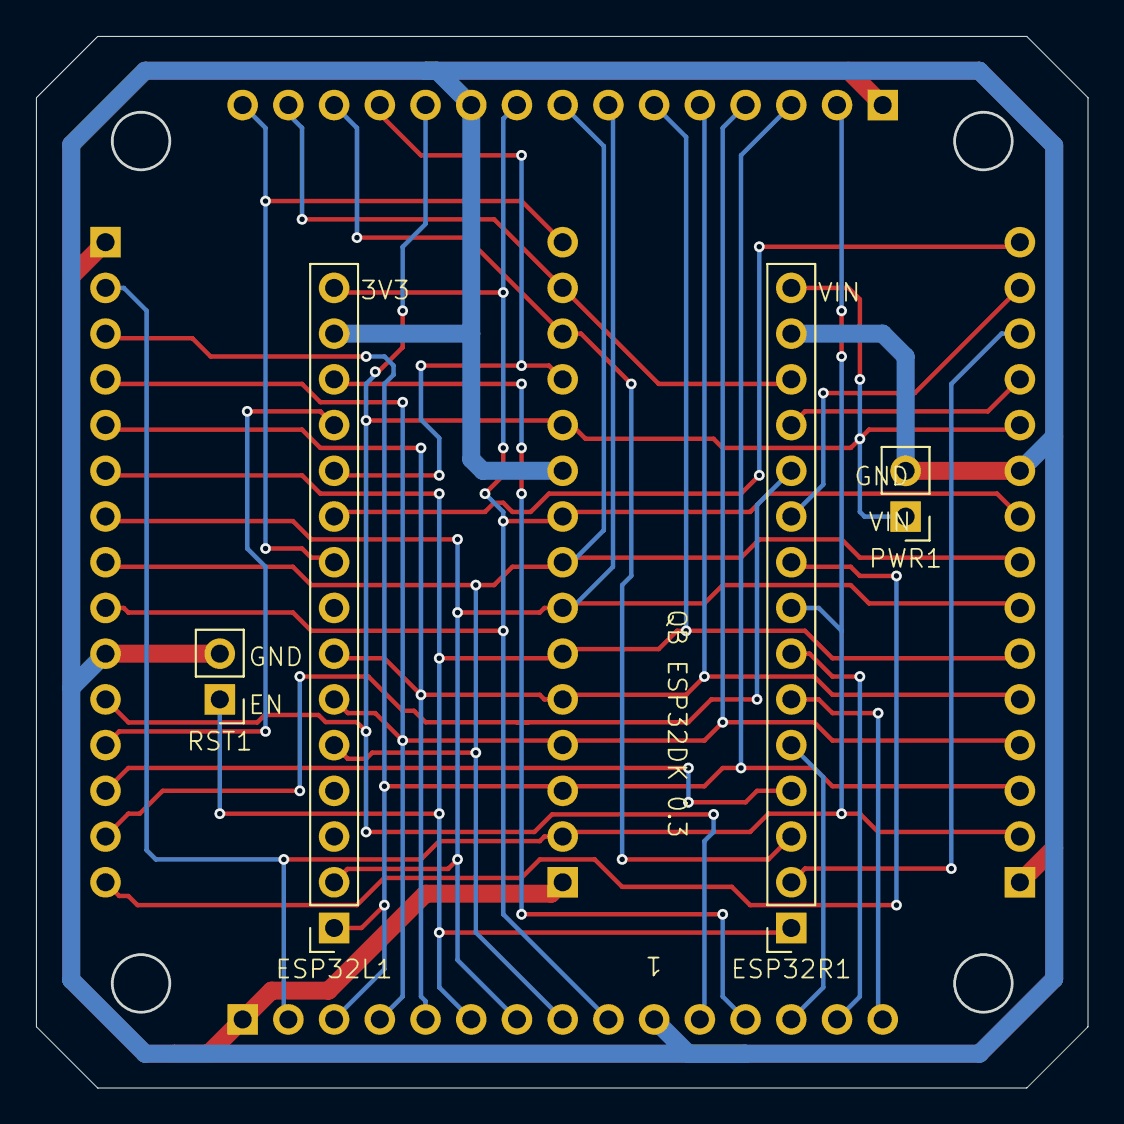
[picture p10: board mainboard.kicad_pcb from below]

Board: 2 copper layers, 58.4 x 58.4 mm, 9 parts (4 on the bottom side), 27 nets.

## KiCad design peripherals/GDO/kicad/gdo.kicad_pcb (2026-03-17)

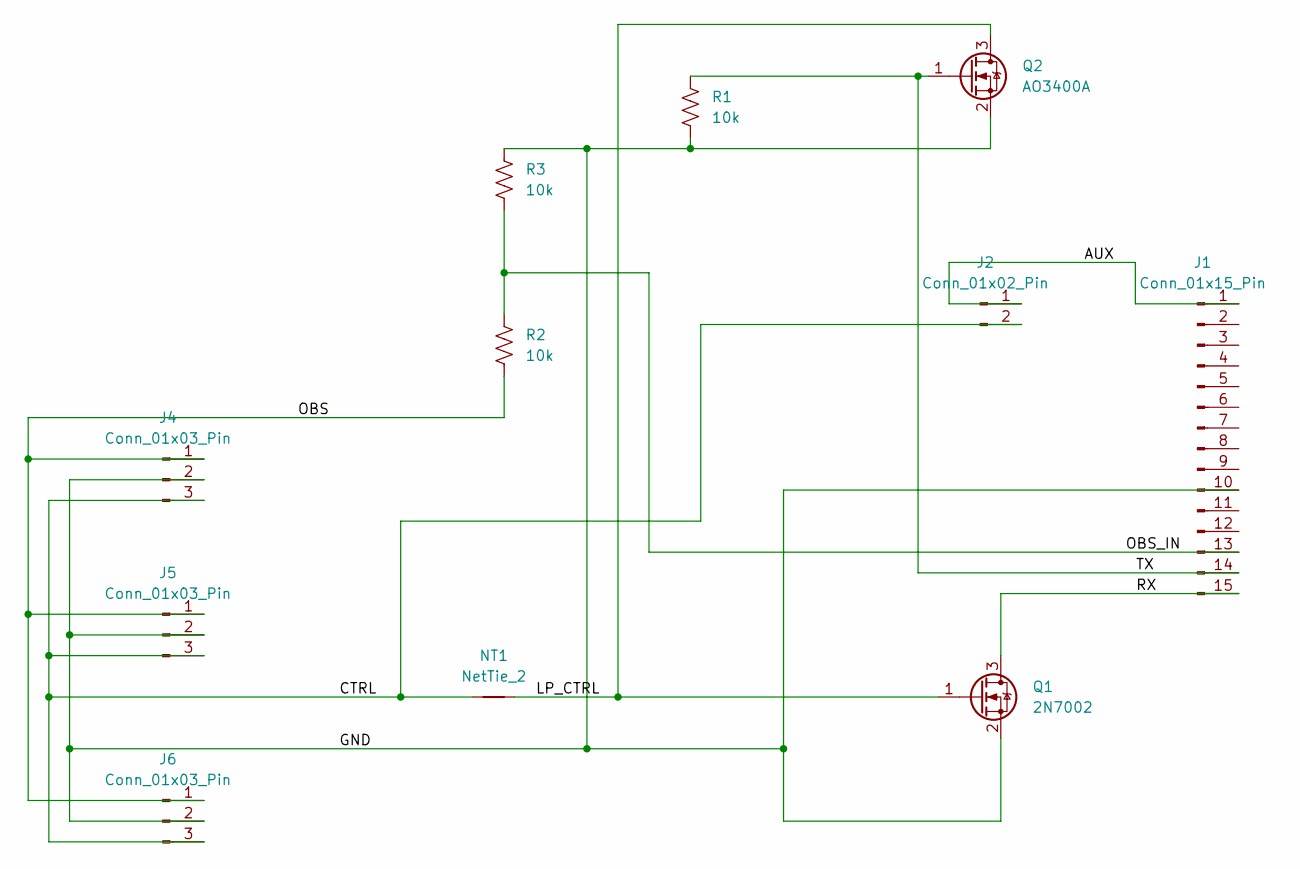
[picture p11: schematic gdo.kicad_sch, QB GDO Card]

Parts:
J1: Conn_01x15_Pin; PinHeader_1x15_P2.54mm_Horizontal
J2: Conn_01x02_Pin; PinHeader_1x02_P2.54mm_Vertical
J4, J5, J6: Conn_01x03_Pin; PinHeader_1x03_P2.54mm_Vertical
NT1: NetTie_2; NetTie-2_THT_Pad1.0mm
Q1: 2N7002; SOT-23
Q2: AO3400A; SOT-23
R1, R2, R3: 10k; R_0805_2012Metric_Pad1.20x1.40mm_HandSolder

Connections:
/AUX: J1.1, J2.1
/CTRL: J2.2, J4.3, J5.3, J6.3, NT1.1
/GND: J1.10, J4.2, J5.2, J6.2, Q1.2 (S), Q2.2 (S), R1.2, R3.1
/LP_CTRL: NT1.2, Q1.1 (G), Q2.3 (D)
/OBS: J4.1, J5.1, J6.1, R2.2
/OBS_IN: J1.13, R2.1, R3.2
/RX: J1.15, Q1.3 (D)
/TX: J1.14, Q2.1 (G), R1.1

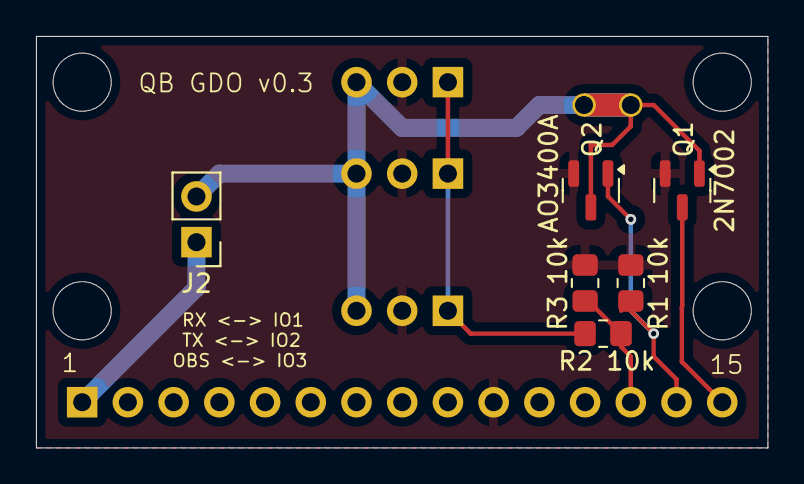
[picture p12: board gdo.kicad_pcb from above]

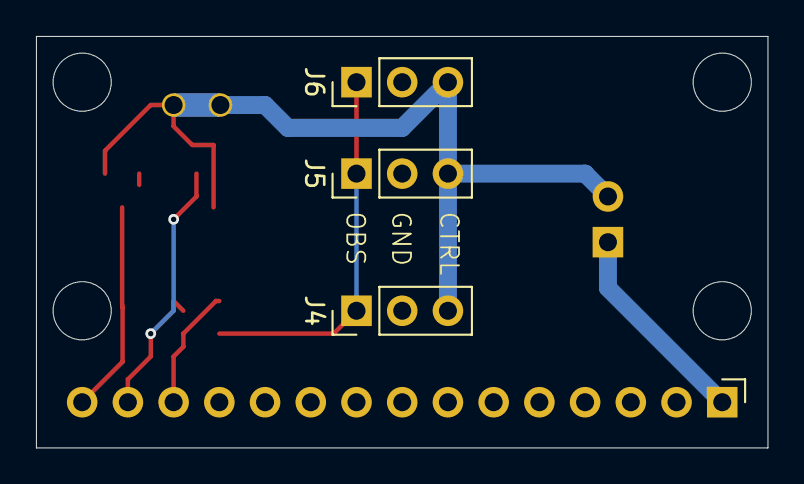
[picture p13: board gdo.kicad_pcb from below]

Board: 2 copper layers, 40.6 x 22.9 mm, 11 parts (5 on the bottom side), 8 nets.

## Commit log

2026-03-17 Initial commit with top level and board files.
    [gdo.kicad_pcb, gdo.kicad_sch, hcsr04.kicad_pcb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]
2026-03-17 Adding README for HC-SR04
    [hcsr04.kicad_pcb, hcsr04.kicad_sch]
2026-03-19 Adding links to enclosure pieces.
2026-03-20 Adding BOM for main board.
    [mainboard.kicad_sch]
2026-03-24 Completing HC-SR04 peripheral, and other minor changes.
    [hcsr04.kicad_sch]
2026-03-25 * Loosening up the spec so that only connector-to-plate distance is specified. Peripherals are free to choose connectors and board thickness, and this may cause the board-to-plate distance to vary. *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
2026-04-02 Adding GDO peripheral BOM, PCBWay project, and enclosure face plate.
    [gdo.kicad_sch]
